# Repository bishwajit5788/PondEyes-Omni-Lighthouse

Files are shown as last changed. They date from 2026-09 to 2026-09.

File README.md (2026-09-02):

# PondEyes Omni-Lighthouse: 360-Degree Multi-Target Radar Platform

[]()
[]()
[]()
[]()
[]()

**PondEyes Omni-Lighthouse** is a high-precision, 360-degree multi-target tracking radar platform engineered for panoramic spatial awareness. It integrates six **Hi-Link HLK-LD2450 24GHz FMCW mmWave radar sensors** arranged radially at 60° increments inside an isolated 6-compartment waveguide cylinder. 

The system leverages a **two-stage distributed embedded architecture**: two high-speed **Teensy 4.1** microcontrollers handle real-time 256k-baud UART frame parsing, trigonometric rotation, and Euclidean seam deduplication, while a **Seeed Studio XIAO ESP32-S3** master coordinator aggregates fused binary streams over an 8 MHz SPI bus and broadcasts structured JSON telemetry over Wi-Fi/MQTT at 10 Hz.

---

## Table of Contents
1. [Architecture & Hardware Bug Fixes](#architecture--hardware-bug-fixes)
2. [Waveguide Hollow Cylinder & RF Isolation](#waveguide-hollow-cylinder--rf-isolation)
3. [Power Management (1S4P Matrix + MT3608)](#power-management-1s4p-matrix--mt3608)
4. [Hardware Pinout & Interconnects](#hardware-pinout--interconnects)
5. [Coordinate Geometry & Rotation Matrix](#coordinate-geometry--rotation-matrix)
6. [Boundary Seam Deduplication & SVG Overlay](#boundary-seam-deduplication--svg-overlay)
7. [MQTT Data Stream Schema](#mqtt-data-stream-schema)
8. [Building & Flashing](#building--flashing)
9. [Configuration Reference](#configuration-reference)

---

## Architecture & Hardware Bug Fixes

```
 ┌────────────────────────────────────────────────────────────────────────────────────────┐
 │                              STAGE 1: REAL-TIME DSP & FUSION                           │
 ├─────────────────────────────────────────┬──────────────────────────────────────────────┤
 │             TEENSY 4.1 (NODE A)         │              TEENSY 4.1 (NODE B)             │
 │          600 MHz ARM Cortex-M7          │           600 MHz ARM Cortex-M7              │
 │                                         │                                              │
 │  [S1 @ 0°]   [S2 @ 60°]   [S3 @ 120°]   │  [S4 @ 180°]  [S5 @ 240°]  [S6 @ 300°]       │
 │   Serial1      Serial2      Serial3     │    Serial1       Serial2      Serial3        │
 │  (256kbaud)   (256kbaud)   (256kbaud)   │   (256kbaud)    (256kbaud)   (256kbaud)      │
 │      │            │            │        │       │             │            │           │
 │      ▼            ▼            ▼        │       ▼             ▼            ▼           │
 │  ┌───────────────────────────────────┐  │  ┌────────────────────────────────────────┐  │
 │  │ 3x UART Ring Buffers (Zero Drops) │  │  │  3x UART Ring Buffers (Zero Drops)     │  │
 │  │ LD2450 Sign-Magnitude Decoders    │  │  │  LD2450 Sign-Magnitude Decoders        │  │
 │  │ 2D Rotation Matrix (0°/60°/120°)  │  │  │  2D Rotation Matrix (180°/240°/300°)   │  │
 │  │ Euclidean Seam Deduplication      │  │  │  Euclidean Seam Deduplication          │  │
 │  │ TSPISlave + Tri-State MISO        │  │  │  TSPISlave + Tri-State MISO            │  │
 │  └─────────────────┬─────────────────┘  │  └───────────────────┬────────────────────┘  │
 └────────────────────┼────────────────────┴──────────────────────┼───────────────────────┘
                      │ (SPI Bus + CS_A + DRDY_A)                 │ (SPI Bus + CS_B + DRDY_B)
                      └─────────────────────────┬─────────────────┘
                                                ▼
 ┌────────────────────────────────────────────────────────────────────────────────────────┐
 │                      STAGE 2: MASTER COORDINATOR & BROADCASTER                         │
 ├────────────────────────────────────────────────────────────────────────────────────────┤
 │                             SEEED STUDIO XIAO ESP32-S3                                 │
 │                              240 MHz Dual-Core LX7                                     │
 │                                                                                        │
 │   • High-Speed Hardware SPI Master Engine (8 MHz Bus Clock)                            │
 │   • Deterministic Multi-Node CS Arbitration & Hardware DRDY Interrupt Handshake        │
 │   • CRC16 Verification & Frame Synchronization                                         │
 │   • Exponential Backoff Wi-Fi Reconnection & Hardware Watchdog                         │
 │   • Zero-Heap-Leak Static Memory (StaticJsonDocument<2048>) @ 10 Hz                    │
 └──────────────────────────────────────────────┬─────────────────────────────────────────┘
                                                │ (10Hz Wi-Fi MQTT)
                                                ▼
 ┌────────────────────────────────────────────────────────────────────────────────────────┐
 │ MQTT BROKER / PONDEYES DASHBOARD                                                       │
 │ Topics: PondEyes/lighthouse/S1..S6  |  PondEyes/lighthouse/fused                       │
 └────────────────────────────────────────────────────────────────────────────────────────┘
```

### Critical Bug Fixes Implemented:
1. **Teensy SPI Hardware Compatibility (`TSPISlave.h`)**:
   - Replaced deprecated SPI slave declarations with `TSPISlave` register-level drivers targeting the i.MX RT1062 LPSPI peripheral.
2. **MISO Line Collision Prevention (Active Tri-State Switching)**:
   - When CS is HIGH (deselected), each Teensy immediately configures its hardware MISO pin (Pin 12) to high-impedance floating mode (`pinMode(12, INPUT);`).
   - MISO is driven as `OUTPUT` (`pinMode(12, OUTPUT);`) **only** when its specific CS line is pulled LOW by the ESP32-S3 master, preventing electrical contention on the shared MISO bus.
3. **Zero-Heap-Leak Static Memory Architecture on ESP32-S3**:
   - Eliminated dynamic heap allocation in the 10 Hz broadcast loop by utilizing a static fixed buffer (`StaticJsonDocument<2048> doc;`), completely preventing heap fragmentation and watchdog resets.
4. **Strict Configuration Validation**:
   - `radar_config.json` fully defines `arena.dimensions_mm: [10000, 10000]` and `arena.center_grid_mm: [5000, 5000]` alongside native integer pin maps.

---

## Waveguide Hollow Cylinder & RF Isolation

The physical chassis of the Omni-Lighthouse consists of a **130 mm diameter hollow cylinder** partitioned into **six 60° isolated radial compartments**.

```
                           [ S1 (0°) ]
                             ▲  ▲
                           /  ││  \
              [ S6 (300°) ] /───┼───\ [ S2 (60°) ]
                   ◄──     │ 1 │ 2 │     ──►
                   ◄──     │───┼───│     ──►
                           │ 6 │ 3 │
              [ S5 (240°) ] \───┼───/ [ S3 (120°) ]
                           \  ││  /
                             ▼  ▼
                          [ S4 (180°) ]
```

### RF Cross-Talk Mitigation:
1. **Operating Band**: 24.00 GHz – 24.25 GHz FMCW radar.
2. **Azimuth FOV**: Each sensor has an effective horizontal beamwidth of ±60° (120° total).
3. **Internal Waveguide Septa**: Each compartment features a 35 mm deep conductive barrier lined with 0.1 mm copper shielding tape to prevent direct line-of-sight transmit lobe bleed into neighboring radar receiver antennas.
4. **Antenna Mounting Radius ($R = 65.0\text{ mm}$)**: Sensor apertures sit flush with the cylinder perimeter.

---

## Power Management (1S4P Matrix + MT3608)

```
 ┌──────────────────────┐      ┌─────────────────────────┐      ┌──────────────────────┐
 │  1S4P 18650 Matrix   │ 3.7V │     MT3608 Step-Up      │ 5.0V │   LC Filter + Rail   │
 │   3.0V - 4.2V Nom    ├─────►│     Boost Converter     ├─────►│ L: 10µH, C: 470µF    ├──► 5V Rail
 │  14,000 mAh (51.8Wh) │      │ (Set: 5.05V, max 3.0A)  │      │ (Decoupling per node)│
 └──────────────────────┘      └─────────────────────────┘      └──────────────────────┘
```

### Power Specifications:
| Subsystem | Operating Voltage | Peak Current | Avg Current | Notes |
| :--- | :--- | :--- | :--- | :--- |
| **6x HLK-LD2450 Radars** | 5.0 V DC | 6x 120 mA = 720 mA | ~550 mA | 24GHz FMCW RF transceivers |
| **2x Teensy 4.1 Nodes** | 5.0 V DC (VIN) | 2x 150 mA = 300 mA | ~200 mA | 600 MHz Cortex-M7 |
| **1x XIAO ESP32-S3** | 5.0 V DC (5V pin) | 350 mA (Wi-Fi TX) | ~120 mA | 2.4GHz 802.11 b/g/n active |
| **Total System Draw** | **5.0 V Rail** | **~1.37 A Peak** | **~870 mA Avg** | **~4.35 Watts** |

- **Battery Matrix**: 1S4P 18650 cells (14,000 mAh @ 3.7V = 51.8 Wh).
- **Runtime**: **10.8 to 14.5 Hours** continuous operation.
- **LC Low-Pass Filter**: $10\mu\text{H}$ inductor + $470\mu\text{F}$ low-ESR capacitor eliminates 1.2 MHz MT3608 switching ripple ($< 15\text{ mV}_\text{p-p}$).

---

## Hardware Pinout & Interconnects

### 1. Teensy 4.1 Node A (Sensors 1, 2, 3)
| Function | Teensy 4.1 Pin | Connected Device | Description |
| :--- | :--- | :--- | :--- |
| **Serial1 RX** | Pin 0 (RX1) | S1 (0°) TX | Sensor 1 256k-baud UART |
| **Serial1 TX** | Pin 1 (TX1) | S1 (0°) RX | Sensor 1 Config (Optional) |
| **Serial2 RX** | Pin 7 (RX2) | S2 (60°) TX | Sensor 2 256k-baud UART |
| **Serial2 TX** | Pin 8 (TX2) | S2 (60°) RX | Sensor 2 Config (Optional) |
| **Serial3 RX** | Pin 14 (RX3)| S3 (120°) TX | Sensor 3 256k-baud UART |
| **Serial3 TX** | Pin 15 (TX3)| S3 (120°) RX | Sensor 3 Config (Optional) |
| **SPI CS** | Pin 10 | XIAO D1 (GPIO 2) | SPI Slave Select (Active LOW) |
| **SPI MOSI** | Pin 11 | XIAO D10 (GPIO 9)| SPI Data In from Master |
| **SPI MISO** | Pin 12 | XIAO D9 (GPIO 8) | Tri-State MISO Data Out |
| **SPI SCK** | Pin 13 | XIAO D8 (GPIO 7) | SPI Clock (8 MHz) |
| **DRDY Handshake**| Pin 2 | XIAO D3 (GPIO 4) | Data Ready Handshake Line |
| **Power VIN** | VIN (5V) | 5.0V Boost Rail | System 5V Power Supply |
| **Ground** | GND | Common Ground | Unified Ground Plane |

### 2. Teensy 4.1 Node B (Sensors 4, 5, 6)
| Function | Teensy 4.1 Pin | Connected Device | Description |
| :--- | :--- | :--- | :--- |
| **Serial1 RX** | Pin 0 (RX1) | S4 (180°) TX | Sensor 4 256k-baud UART |
| **Serial1 TX** | Pin 1 (TX1) | S4 (180°) RX | Sensor 4 Config (Optional) |
| **Serial2 RX** | Pin 7 (RX2) | S5 (240°) TX | Sensor 5 256k-baud UART |
| **Serial2 TX** | Pin 8 (TX2) | S5 (240°) RX | Sensor 5 Config (Optional) |
| **Serial3 RX** | Pin 14 (RX3)| S6 (300°) TX | Sensor 6 256k-baud UART |
| **Serial3 TX** | Pin 15 (TX3)| S6 (300°) RX | Sensor 6 Config (Optional) |
| **SPI CS** | Pin 10 | XIAO D2 (GPIO 3) | SPI Slave Select (Active LOW) |
| **SPI MOSI** | Pin 11 | XIAO D10 (GPIO 9)| SPI Data In from Master |
| **SPI MISO** | Pin 12 | XIAO D9 (GPIO 8) | Tri-State MISO Data Out |
| **SPI SCK** | Pin 13 | XIAO D8 (GPIO 7) | SPI Clock (8 MHz) |
| **DRDY Handshake**| Pin 2 | XIAO D4 (GPIO 5) | Data Ready Handshake Line |
| **Power VIN** | VIN (5V) | 5.0V Boost Rail | System 5V Power Supply |
| **Ground** | GND | Common Ground | Unified Ground Plane |

### 3. Seeed Studio XIAO ESP32-S3 Master Coordinator
| Function | XIAO Pin | Connected Device | Description |
| :--- | :--- | :--- | :--- |
| **SPI SCK** | D8 (GPIO 7) | Node A Pin 13 & Node B Pin 13 | Master SPI Clock (8 MHz) |
| **SPI MISO**| D9 (GPIO 8) | Node A Pin 12 & Node B Pin 12 | Shared Master SPI MISO In |
| **SPI MOSI**| D10 (GPIO 9)| Node A Pin 11 & Node B Pin 11 | Shared Master SPI MOSI Out |
| **CS Node A**| D1 (GPIO 2) | Node A Pin 10 | Node A Chip Select |
| **CS Node B**| D2 (GPIO 3) | Node B Pin 10 | Node B Chip Select |
| **DRDY Node A**| D3 (GPIO 4) | Node A Pin 2 | Node A Data Ready Interrupt |
| **DRDY Node B**| D4 (GPIO 5) | Node B Pin 2 | Node B Data Ready Interrupt |
| **Status LED** | LED_BUILTIN (GPIO 21) | Onboard LED | Connection / Error Indicator |
| **Power 5V** | 5V Pin | 5.0V Boost Rail | System 5V Power Supply |
| **Ground** | GND | Common Ground | Unified Ground Plane |

---

## Coordinate Geometry & Rotation Matrix

- **Arena Center**: $(X_c, Y_c) = (5000.0\text{ mm}, 5000.0\text{ mm})$.
- **Sensor Radius**: $R = 65.0\text{ mm}$.
- **Sensor Angles $\theta_k$**: $0^\circ, 60^\circ, 120^\circ, 180^\circ, 240^\circ, 300^\circ$ clockwise from North ($+Y$).

$$\mathbf{X_{\text{global}}} = X_c + R \cdot \sin(\theta_k) + X_{\text{local}} \cdot \cos(\theta_k) + Y_{\text{local}} \cdot \sin(\theta_k)$$
$$\mathbf{Y_{\text{global}}} = Y_c + R \cdot \cos(\theta_k) - X_{\text{local}} \cdot \sin(\theta_k) + Y_{\text{local}} \cdot \cos(\theta_k)$$

---

## Boundary Seam Deduplication & SVG Overlay

Adjacent sensors overlap by 60° across boundary seams (at 30°, 90°, 150°, 210°, 270°, 330°). If distance between detections from different sensors is $< 500\text{ mm}$, they are fused into a single track $(\frac{X_i+X_j}{2}, \frac{Y_i+Y_j}{2})$.

### Dashboard SVG Overlay Code (`map.svg`):
```xml
<svg viewBox="0 0 10000 10000" width="100%" height="100%" xmlns="http://www.w3.org/2000/svg">
  <!-- Unified Arena Grid -->
  <rect width="10000" height="10000" fill="#0D1117" stroke="#30363D" stroke-width="2"/>
  
  <!-- Boundary Seam Rays for Visual Calibration -->
  <g id="seam-overlays" stroke="#FF2A2A" stroke-width="0.75pt" stroke-dasharray="4 2">
    <!-- Seam 1: 30° -->
    <line x1="5000" y1="5000" x2="8000" y2="10196" />
    <!-- Seam 2: 90° -->
    <line x1="5000" y1="5000" x2="11000" y2="5000" />
    <!-- Seam 3: 150° -->
    <line x1="5000" y1="5000" x2="8000" y2="-196" />
    <!-- Seam 4: 210° -->
    <line x1="5000" y1="5000" x2="2000" y2="-196" />
    <!-- Seam 5: 270° -->
    <line x1="5000" y1="5000" x2="-1000" y2="5000" />
    <!-- Seam 6: 330° -->
    <line x1="5000" y1="5000" x2="2000" y2="10196" />
  </g>
  
  <!-- Central Lighthouse Body -->
  <circle cx="5000" cy="5000" r="65" fill="#58A6FF" stroke="#FFFFFF" stroke-width="2"/>
</svg>
```

---

## MQTT Data Stream Schema

### Fused Telemetry Topic (`PondEyes/lighthouse/fused` @ 10 Hz)
```json
{
  "system": "PondEyes Omni-Lighthouse",
  "timestamp_ms": 145230,
  "rate_hz": 10,
  "total_active_targets": 2,
  "fused_targets": [
    {
      "sensor": 1,
      "track_id": 1,
      "x": 5120,
      "y": 7450,
      "speed": -24,
      "distance": 2450,
      "fused": false,
      "source_mask": 1
    },
    {
      "sensor": 2,
      "track_id": 1,
      "x": 6850,
      "y": 6200,
      "speed": 0,
      "distance": 2150,
      "fused": true,
      "source_mask": 3
    }
  ]
}
```

---

## Building & Flashing

```bash
# Build all firmware binaries
pio run

# Flash Teensy Node A
pio run -e teensy_node_a --target upload

# Flash Teensy Node B
pio run -e teensy_node_b --target upload

# Flash Seeed Studio XIAO ESP32-S3
pio run -e xiao_broadcaster --target upload
```

---

## Live 360° Tracking Canvas & Simulator

Run the real-time PyGame 360° tracking canvas and mock radar telemetry generator:

```bash
# 1. Install dependencies
pip install pygame paho-mqtt

# 2. Run the radar telemetry simulator (10 Hz mock feed)
python3 simulate_radar.py

# 3. In another terminal, launch the live visualization canvas
python3 main.py
```

---

## License

Distributed under the MIT License. See `LICENSE` for details.

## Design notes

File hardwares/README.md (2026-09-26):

# PondEyes Omni-Lighthouse — Hardware Inventory

This directory contains photographs of the physical hardware received for the PondEyes Omni-Lighthouse prototype.

## Hardware Photo Inventory

### 01 — HLK-LD2450 Radar Modules

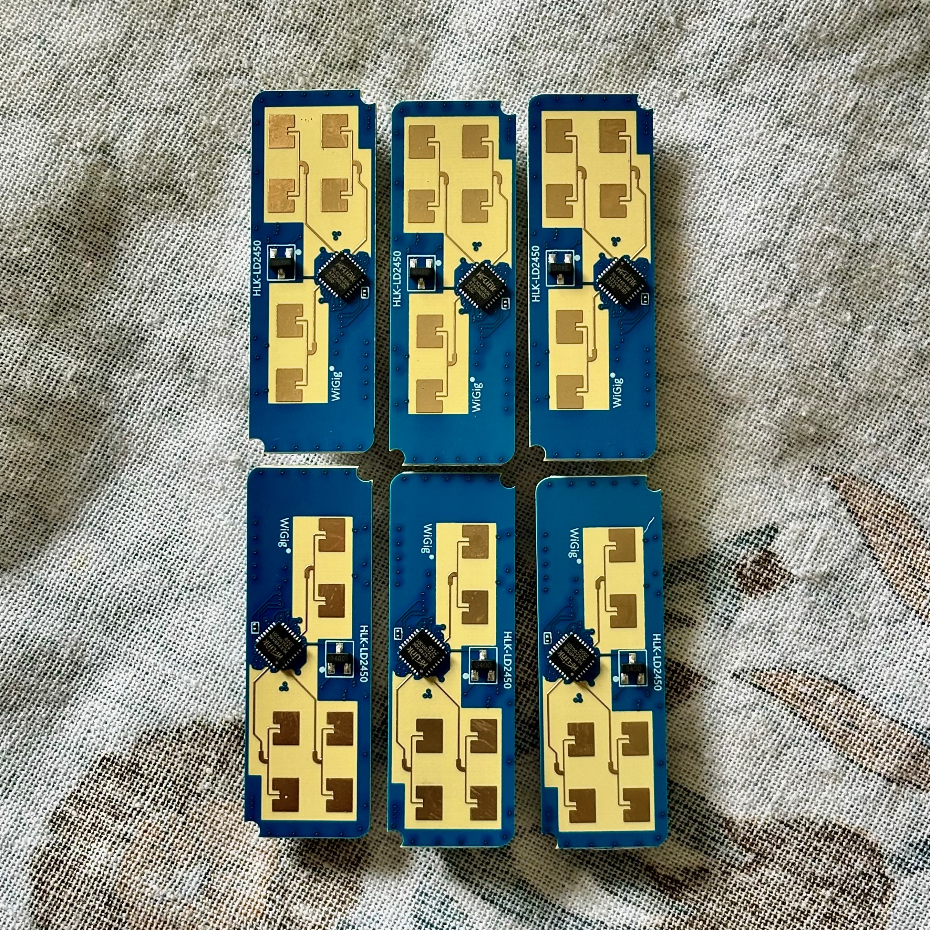
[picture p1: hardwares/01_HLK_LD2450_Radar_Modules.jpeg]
Six HLK-LD2450 radar modules


**File:**
`01_HLK_LD2450_Radar_Modules.jpeg`

**Description:**
Photograph showing six Hi-Link HLK-LD2450 24 GHz FMCW radar modules.

**Quantity visible:**
6

**Component:**
Hi-Link HLK-LD2450

**Role in PondEyes:**
Six radar modules are used as the distributed 360-degree sensing array, positioned around the cylindrical enclosure at 60-degree angular intervals.

**Important:**
The photograph documents the physical modules received. Do not claim electrical specifications that cannot be established from the photograph alone.

---

### 02 — 18650 Battery Cells and BMS

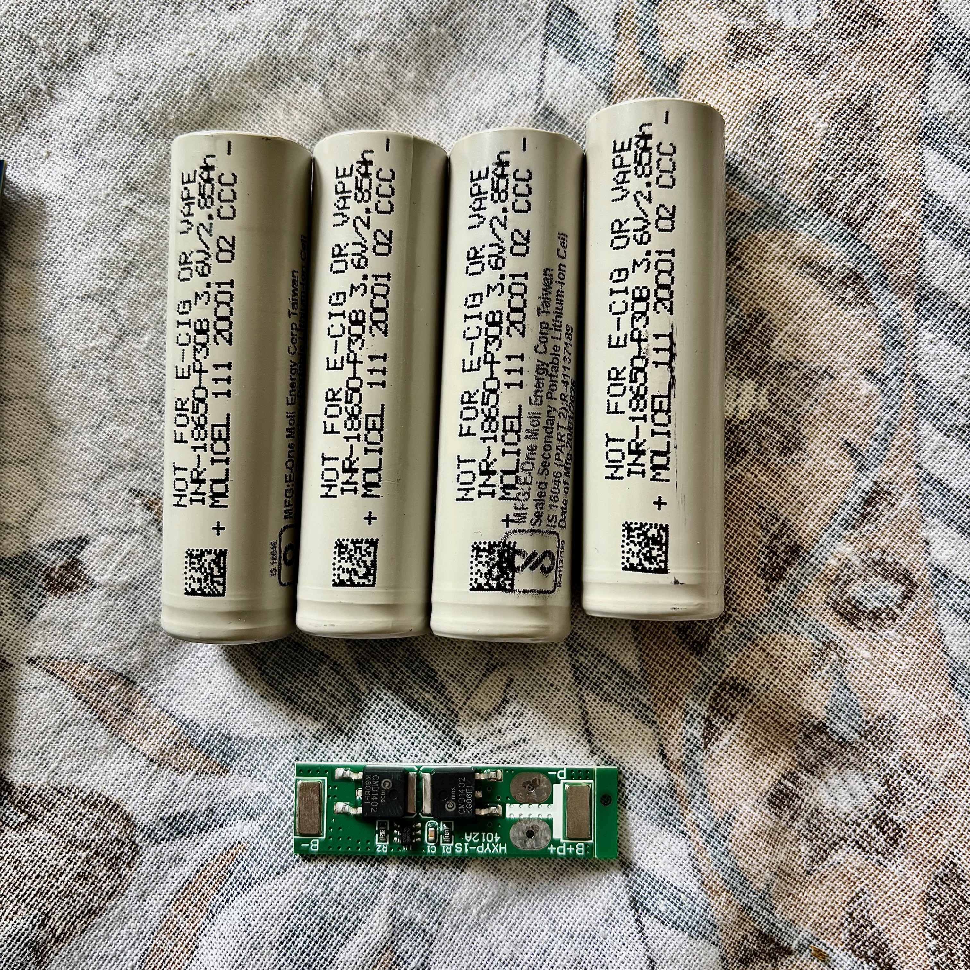
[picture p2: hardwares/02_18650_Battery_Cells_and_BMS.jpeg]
Four 18650 battery cells and battery protection/BMS PCB


**File:**
`02_18650_Battery_Cells_and_BMS.jpeg`

**Description:**
Photograph showing four cylindrical 18650 lithium-ion cells and a small battery protection/BMS PCB.

**Visible components:**
- 4 × 18650 cylindrical Li-ion cells
- 1 × battery protection/BMS PCB

**Visible cell markings:**
- `NOT FOR E-CIG OR VAPE`
- `INR-18650-P30B 3.6V/2.85Ah`
- `+ MOLICEL 111 20C01 02 CCC -`
- `MFG: E-One Moli Energy Corp Taiwan`
- `Sealed Secondary Portable Lithium-ion Cell`
- `IS 16046 (PART 2)/IEC 62133-2`
- `Date of Mfg 20/01/2026`

**BMS PCB note:**
Visible silkscreen marking indicates `HXYP-1S-4012A` with solder pads `B-`, `B+`, `P+`, `P-`. Exact BMS model/rating requires verification from the PCB marking or datasheet.

---

### 03 — AiSHi Electrolytic Capacitors

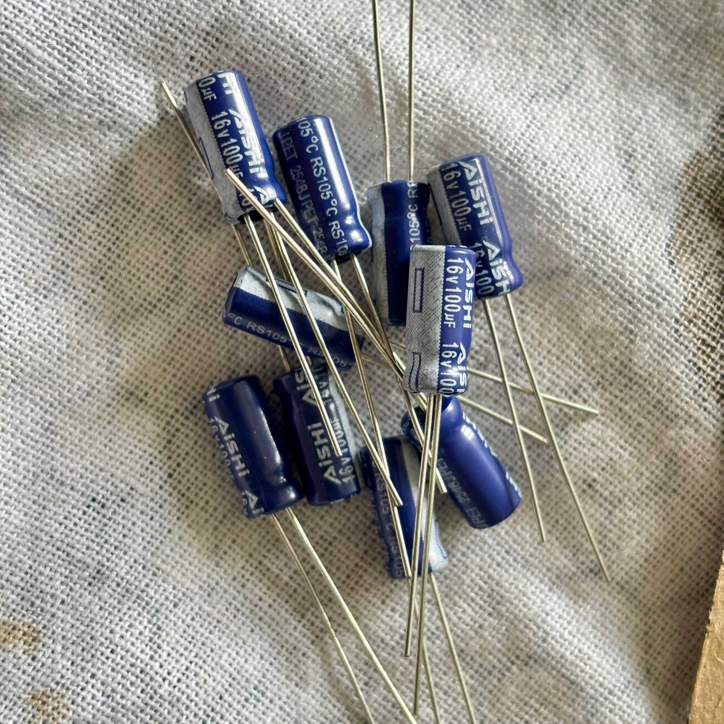
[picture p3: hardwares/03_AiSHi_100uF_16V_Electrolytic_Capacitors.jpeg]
Blue AiSHi electrolytic capacitors marked 100µF 16V


**File:**
`03_AiSHi_100uF_16V_Electrolytic_Capacitors.jpeg`

**Description:**
Photograph showing blue radial electrolytic capacitors.

**Visible marking:**
- `AiSHi`
- `100µF`
- `16V`
- `105°C RS105°C`
- `2548J PET`

**Component:**
AiSHi 100 µF, 16 V electrolytic capacitor.

**Purpose in the PondEyes design:**
Power-rail bulk/decoupling capacitance associated with the sensor/electronics power system.

**Quantity visible:**
Multiple visible (loose radial leads). Visible quantity: not conclusively countable from photograph alone.

---

### 04 — 0.1µF 35V Tantalum Capacitors

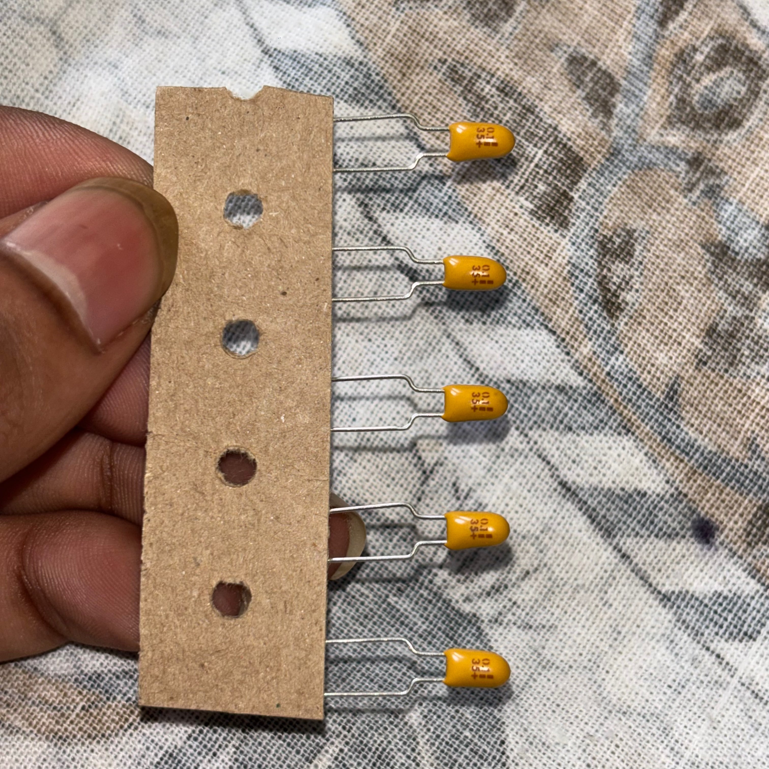
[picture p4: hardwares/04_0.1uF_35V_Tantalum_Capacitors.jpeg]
Yellow axial/lead capacitors on cardboard strip


**File:**
`04_0.1uF_35V_Tantalum_Capacitors.jpeg`

**Description:**
Photograph showing yellow axial/lead capacitors mounted on a temporary cardboard strip.

**Visible marking:**
- `0.1µF`
- `35V`

**Component:**
0.1 µF, 35 V capacitor.

**Package / Style:**
Yellow bead / dipped radial-lead capacitor mounted on a punched cardboard component carrier strip.

**Note:**
Documented exactly as visible. No specific manufacturer markings are established from the photograph alone. Electrical behavior is documented only to the marked 0.1 µF, 35 V rating.

---

### 05 — Teensy, XIAO ESP32-S3, Antenna and RF Hardware

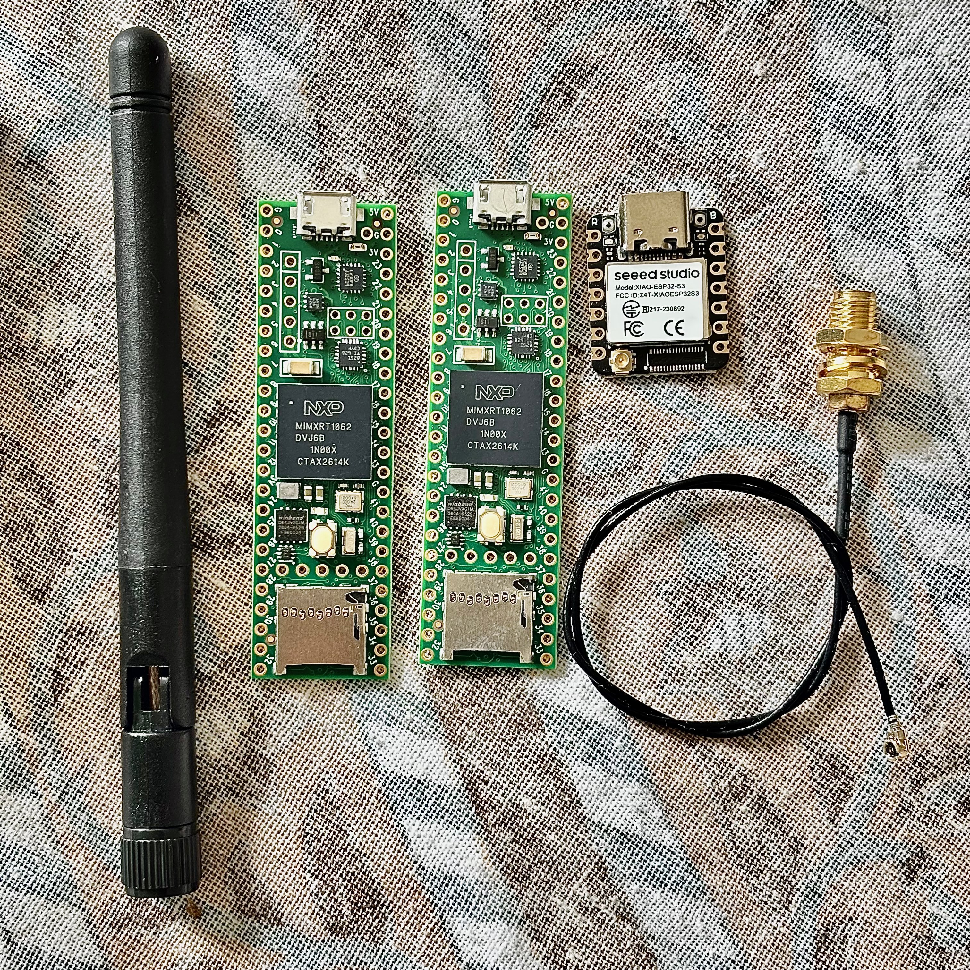
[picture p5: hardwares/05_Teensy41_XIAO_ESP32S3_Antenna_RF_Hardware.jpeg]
Two Teensy 4.1 boards, XIAO ESP32-S3, external antenna and RF coaxial hardware


**File:**
`05_Teensy41_XIAO_ESP32S3_Antenna_RF_Hardware.jpeg`

**Description:**
Photograph showing:
- 2 × Teensy 4.1 development boards (NXP MIMXRT1062 processor)
- 1 × Seeed Studio XIAO ESP32-S3 development board (Model: XIAO-ESP32-S3, FCC ID: Z4T-XIAOESP32S3)
- 1 × external antenna
- RF coaxial cable
- RF connector/bulkhead hardware

**Role in PondEyes:**
- The Teensy boards are the two primary radar-processing/controller boards in the PondEyes architecture.
- The XIAO ESP32-S3 is the network/broadcast controller.
- The antenna and coaxial hardware are intended for the wireless/RF interface.

Do not infer connector standards unless visible markings or dimensions establish them.

---

### 06 — Complete PondEyes Hardware Inventory

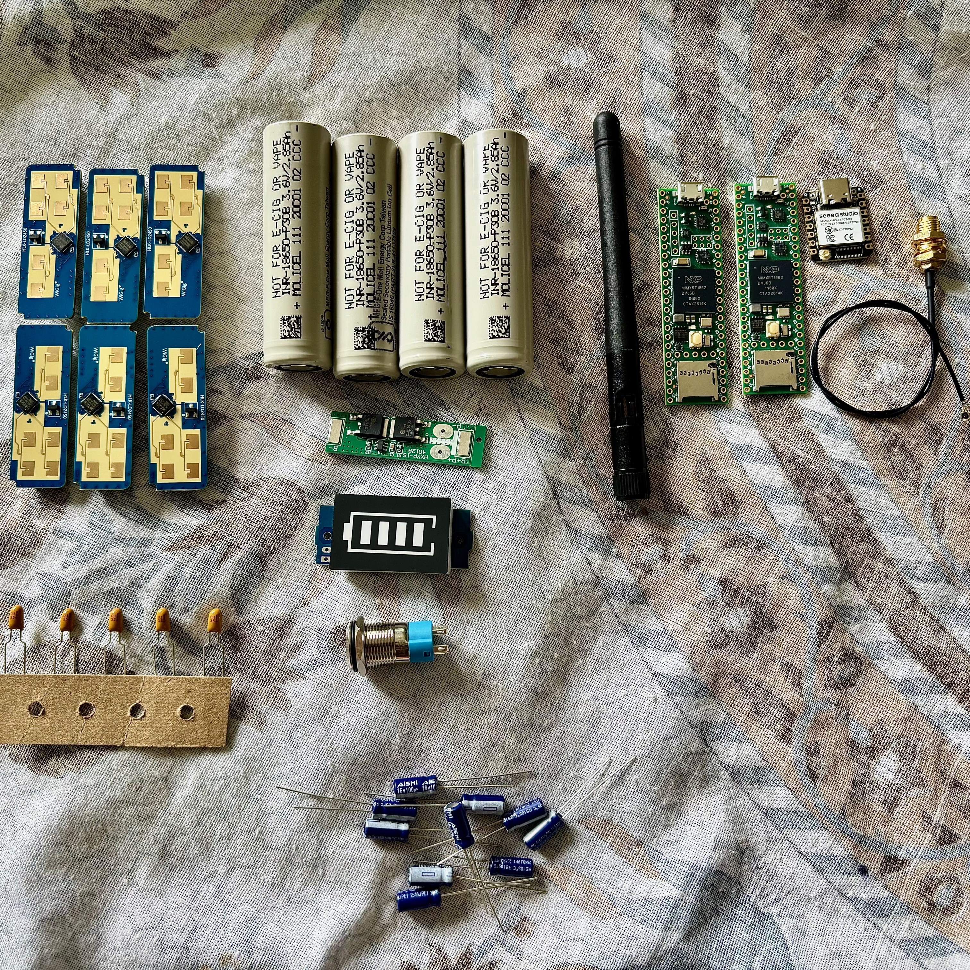
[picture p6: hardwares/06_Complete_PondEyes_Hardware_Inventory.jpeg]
Overall PondEyes hardware inventory showing major components together


**File:**
`06_Complete_PondEyes_Hardware_Inventory.jpeg`

**Description:**
Overall photograph documenting the physical hardware received for the PondEyes Omni-Lighthouse prototype.

The photograph includes the major hardware groups:
- 6 × HLK-LD2450 radar modules
- 18650 battery cells
- Battery protection/BMS PCB
- Teensy 4.1 boards
- XIAO ESP32-S3
- External antenna
- RF cable/connector hardware
- Electrolytic capacitors
- Yellow capacitors
- Battery indicator/display module
- Panel-mount switch/button
- Additional visible prototype electronics/components

Only identify a component specifically when it is clearly visible or established by its marking.

---

## Component Summary Table

| Category | Component | Quantity Visible | Purpose |
|---|---|---:|---|
| Radar | Hi-Link HLK-LD2450 | 6 | 24 GHz radar sensing |
| Controller | Teensy 4.1 | 2 | Radar data processing/aggregation |
| Network Controller | Seeed Studio XIAO ESP32-S3 | 1 | Wireless/network broadcasting |
| Battery | 18650 Li-ion cells | 4 | Battery energy storage |
| Protection | Battery BMS/protection PCB | 1 visible | Battery protection |
| Bulk capacitor | AiSHi 100 µF 16 V electrolytic | Multiple visible | Power filtering/decoupling |
| Decoupling capacitor | 0.1 µF 35 V capacitors | Multiple visible | High-frequency decoupling |
| RF | External antenna | 1 | Wireless/RF interface |
| RF hardware | Coax/connector/bulkhead | 1 set visible | RF connection |
| User interface | Panel-mount switch/button | 1 visible | Power/control interface |
| Indicator | Battery indicator/display | 1 visible | Battery status indication |

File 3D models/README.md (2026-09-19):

# PondEyes Omni-Lighthouse — 3D Models

This directory contains the mechanical CAD exports and dimensional reference for the PondEyes Omni-Lighthouse enclosure.

## 3D model files

### Blender source files

The `.blend` files are the editable Blender source models used to create the corresponding STL exports.

- `bottom_tot.blend` — editable Blender source for the bottom service-cap assembly
- `sensor_tot.blend` — editable Blender source for the six-sensor external mounting assembly
- `top_tot.blend` — editable Blender source for the top cap assembly

### STL exports

The STL files are the 3D-printable mesh exports corresponding to the Blender source files.

- `top_tot.stl` — top cap export
- `sensor_tot.stl` — six-sensor external mounting export
- `bottom_tot.stl` — bottom service-cap export

### Documentation

- `PondEyes_Enclosure_Spec.md` — hardware and enclosure dimensions

## Source-to-STL mapping

| Blender source | STL export | Purpose |
|---|---|---|
| `top_tot.blend` | `top_tot.stl` | Top cap |
| `sensor_tot.blend` | `sensor_tot.stl` | Six-radar sensor mounting body |
| `bottom_tot.blend` | `bottom_tot.stl` | Bottom service cap |

## Mechanical target

**100 mm outer diameter × 150 mm body height × 3 mm nominal wall**

Six HLK-LD2450 radar modules are arranged externally at 60° intervals. Two Teensy 4.1 boards and one XIAO ESP32-S3 are intended to fit inside the enclosure.

## CAD workflow

The recommended workflow is:

1. Edit the corresponding `.blend` source in Blender.
2. Verify dimensions, clearances, manifold geometry, and assembly interfaces.
3. Export the updated component as STL for slicing/3D printing.
4. Keep the Blender source and STL export together so the printable mesh remains traceable to its editable CAD source.

> **Note:** The Blender files are the editable design sources; the STL files are mesh exports intended for fabrication and should not be treated as the primary editable CAD source.

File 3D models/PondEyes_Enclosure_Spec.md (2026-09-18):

# PondEyes Omni-Lighthouse — 3D Model & Hardware Specification

## Current enclosure target

- Main body: cylindrical handheld enclosure
- Main body outer diameter: 100 mm
- Outer radius: 50 mm
- Nominal wall thickness: 3 mm
- Inner diameter: 94 mm
- Inner radius: 47 mm
- Main body height: 150 mm
- Printer target: Bambu Lab A1
- Nozzle: 0.4 mm

## Radar sensors

### Hi-Link HLK-LD2450

- Quantity: 6
- Module dimensions: 44 mm × 15 mm
- Mounting: external, low-profile cradles
- Sensor angles: 0°, 60°, 120°, 180°, 240°, 300°
- Opposing pairs: S1/S4, S2/S5, S3/S6
- Nominal sensor fit envelope with 0.2 mm per-side clearance: 44.4 mm × 15.4 mm

## Development boards

### Teensy 4.1

- Quantity: 2
- Approximate board dimensions: 61 mm × 17.8 mm
- Mounted internally
- Internal holder/rail system should preserve service access and wiring clearance

### Seeed Studio XIAO ESP32-S3

- Quantity: 1
- Board dimensions: 21 mm × 17.8 mm
- Mounted internally
- Associated with the top/antenna assembly

## Caps

### Top cap

- Removable
- Hollow internal volume
- Centered antenna pass-through/support
- Antenna hole target: Ø6.5 mm

### Bottom service cap

- Removable
- Closed bottom surface
- Hollow interior
- Female helical thread on the inside of the cap
- Mates with the enclosure's external male helical thread
- Intended to lock/unlock by rotation
- Thread fit must be validated physically for the selected FDM material and print orientation

## CAD / manufacturing notes

The STL exports are the current supplied CAD revision. Before fabrication, verify the STL dimensions against the master dimensions above and perform a test print of the threaded interface. RF performance and radar-to-radar interference are not proven by mechanical CAD alone.

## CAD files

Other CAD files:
3D models/sensor_tot.stl
3D models/bottom_tot.stl
3D models/top_tot.stl

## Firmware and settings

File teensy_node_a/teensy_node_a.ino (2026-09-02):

/**
 * ============================================================================
 * PondEyes Omni-Lighthouse - Teensy Node A Firmware
 * Microcontroller: Teensy 4.1 (600 MHz ARM Cortex-M7)
 * ============================================================================
 */

#if __has_include(<Arduino.h>)
#include <Arduino.h>
#endif
#if __has_include(<WProgram.h>)
#include <WProgram.h>
#endif
#if __has_include(<usb_serial.h>)
#include <usb_serial.h>
#endif
#if __has_include(<HardwareSerial.h>)
#include <HardwareSerial.h>
#endif
#if __has_include(<Stream.h>)
#include <Stream.h>
#endif
#if __has_include(<SPI.h>)
#include <SPI.h>
#endif
#if __has_include(<TSPISlave.h>)
#include <TSPISlave.h>
#endif
#include <math.h>
#include <string.h>
#include <stdint.h>
#include <stdbool.h>

// Arduino Core Timing & Utility Prototypes (C-linkage for IDE / Clangd / Toolchains)
#ifdef __cplusplus
extern "C" {
#endif
void delay(uint32_t ms);
void delayMicroseconds(uint32_t us);
unsigned long millis(void);
unsigned long micros(void);
void yield(void);
#ifdef __cplusplus
}
#endif

// Fallback declarations for IDE language servers / Clangd indexers when standalone
#if !defined(ARDUINO) && !defined(TEENSYDUINO)
#ifndef HIGH
#define HIGH 1
#define LOW  0
#endif
#ifndef INPUT
#define INPUT 0
#define OUTPUT 1
#define INPUT_PULLUP 2
#endif
#ifndef CHANGE
#define CHANGE 1
#define FALLING 2
#define RISING 3
#endif

#ifndef F
#define F(str) (str)
#endif

#ifdef __cplusplus
class Print {
public:
    virtual ~Print() {}
    virtual size_t write(uint8_t) = 0;
    virtual size_t write(const uint8_t*, size_t size) { return size; }
    size_t print(const char*) { return 0; }
    size_t print(char) { return 0; }
    size_t print(int, int = 10) { return 0; }
    size_t print(unsigned int, int = 10) { return 0; }
    size_t print(long, int = 10) { return 0; }
    size_t print(unsigned long, int = 10) { return 0; }
    size_t print(double, int = 2) { return 0; }
    size_t println(const char* = "") { return 0; }
    size_t println(char) { return 0; }
    size_t println(int, int = 10) { return 0; }
    size_t println(unsigned int, int = 10) { return 0; }
    size_t println(long, int = 10) { return 0; }
    size_t println(unsigned long, int = 10) { return 0; }
    size_t println(double, int = 2) { return 0; }
    int printf(const char*, ...) __attribute__((format(printf, 2, 3))) { return 0; }
};

class Stream : public Print {
public:
    virtual int available() = 0;
    virtual int read() = 0;
    virtual int peek() = 0;
    virtual void flush() {}
};

class HardwareSerial : public Stream {
public:
    void begin(uint32_t) {}
    void end() {}
    virtual int available() override { return 0; }
    virtual int read() override { return -1; }
    virtual int peek() override { return -1; }
    virtual void flush() override {}
    virtual size_t write(uint8_t) override { return 1; }
    using Print::write;
};

class usb_serial_class : public Stream {
public:
    void begin(uint32_t) {}
    void end() {}
    virtual int available() override { return 0; }
    virtual int read() override { return -1; }
    virtual int peek() override { return -1; }
    virtual void flush() override {}
    virtual size_t write(uint8_t) override { return 1; }
    using Print::write;
    operator bool() { return true; }
};

extern usb_serial_class Serial;
extern HardwareSerial Serial1;
extern HardwareSerial Serial2;
extern HardwareSerial Serial3;
#endif // __cplusplus
#endif // !defined(ARDUINO) && !defined(TEENSYDUINO)

#if __has_include("../include/pondeyes_protocol.h")
#include "../include/pondeyes_protocol.h"
#elif __has_include("include/pondeyes_protocol.h")
#include "include/pondeyes_protocol.h"
#else
#include "pondeyes_protocol.h"
#endif

// ============================================================================
// HARDWARE PIN DEFINITIONS & CONSTANTS
// ============================================================================
#define NODE_ID                     NODE_ID_A

// Teensy 4.1 Hardware SPI0 Pins
#define PIN_SPI_CS                  10  // SPI Chip Select (Input from ESP32-S3)
#define PIN_SPI_MOSI                11  // SPI MOSI (Input from ESP32-S3)
#define PIN_SPI_MISO                12  // SPI MISO (Tri-state Output to ESP32-S3)
#define PIN_SPI_SCK                 13  // SPI Clock (Input from ESP32-S3)
#define PIN_SPI_DRDY                2   // Data Ready Handshake (Output to ESP32-S3)
#define PIN_STATUS_LED              13  // Onboard Diagnostic LED

// Sensor Mapping for Node A
#define S1_ID                       1
#define S2_ID                       2
#define S3_ID                       3

#define S1_ANGLE_DEG                0.0f
#define S2_ANGLE_DEG                60.0f
#define S3_ANGLE_DEG                120.0f

#define DEG_TO_RAD_F                (3.14159265358979323846f / 180.0f)
#define PARSER_FRAME_LEN            30

// ============================================================================
// SENSOR PRECOMPUTED GEOMETRY TABLE
// ============================================================================
typedef struct {
    uint8_t  sensor_id;
    float    angle_deg;
    float    angle_rad;
    float    sin_val;
    float    cos_val;
    float    mount_x_mm;
    float    mount_y_mm;
} SensorGeometry_t;

static SensorGeometry_t g_sensors[3];

// ============================================================================
// LD2450 BINARY FRAME PARSER STATE MACHINE
// ============================================================================
typedef enum {
    STATE_WAIT_HEADER_0 = 0,
    STATE_WAIT_HEADER_1,
    STATE_WAIT_HEADER_2,
    STATE_WAIT_HEADER_3,
    STATE_READ_PAYLOAD,
    STATE_WAIT_TAIL_0,
    STATE_WAIT_TAIL_1
} ParserState_t;

typedef struct {
    HardwareSerial* serial;
    uint8_t         sensor_id;
    ParserState_t   state;
    uint8_t         payload_buf[24];
    uint8_t         payload_idx;
    uint32_t        packets_parsed;
    uint32_t        frame_errors;
    LD2450_RawTarget_t raw_targets[MAX_TARGETS_PER_SENSOR];
    bool            new_data_available;
} SensorPort_t;

static SensorPort_t g_ports[3];

// ============================================================================
// SPI SLAVE & PACKET BUFFERING
// ============================================================================
static TSPISlave           g_spi_slave = TSPISlave(SPI, PIN_SPI_MISO, PIN_SPI_MOSI, PIN_SPI_SCK, PIN_SPI_CS);
static PondEyesSpiPacket_t g_tx_packet;
static volatile bool       g_cs_active = false;
static volatile uint16_t   g_packet_sequence = 0;
static uint32_t            g_last_debug_print_ms = 0;

static PondEyesTarget_t    g_transformed_targets[MAX_TARGETS_PER_NODE];
static uint8_t             g_transformed_count = 0;

void init_sensor_geometry();
void init_uart_ports();
void init_spi_slave_interface();
void process_uart_port(SensorPort_t* port);
void parse_raw_payload(SensorPort_t* port);
void transform_targets_to_global();
void deduplicate_seam_targets();
void prepare_spi_packet();
void isr_cs_pin_transition();

void setup() {
    Serial.begin(115200);
    pinMode(PIN_STATUS_LED, OUTPUT);
    digitalWrite(PIN_STATUS_LED, HIGH);

    delay(1000);
    Serial.println(F("=================================================="));
    Serial.println(F(" PondEyes Omni-Lighthouse: TEENSY NODE A"));
    Serial.println(F(" Node ID: 0x0A | S1@0°, S2@60°, S3@120°"));
    Serial.println(F(" Baudrate: 256k | TSPISlave + Tri-State MISO"));
    Serial.println(F("=================================================="));

    init_sensor_geometry();
    init_uart_ports();
    init_spi_slave_interface();

    digitalWrite(PIN_STATUS_LED, LOW);
    Serial.println(F("[Node A] Initialization successful. System active."));
}

void init_sensor_geometry() {
    float angles[3] = { S1_ANGLE_DEG, S2_ANGLE_DEG, S3_ANGLE_DEG };
    uint8_t ids[3]  = { S1_ID, S2_ID, S3_ID };

    for (int i = 0; i < 3; i++) {
        g_sensors[i].sensor_id  = ids[i];
        g_sensors[i].angle_deg  = angles[i];
        g_sensors[i].angle_rad  = angles[i] * DEG_TO_RAD_F;
        g_sensors[i].sin_val    = sinf(g_sensors[i].angle_rad);
        g_sensors[i].cos_val    = cosf(g_sensors[i].angle_rad);
        g_sensors[i].mount_x_mm = LIGHTHOUSE_RADIUS_MM * g_sensors[i].sin_val;
        g_sensors[i].mount_y_mm = LIGHTHOUSE_RADIUS_MM * g_sensors[i].cos_val;
    }
}

void init_uart_ports() {
    Serial1.begin(LD2450_UART_BAUD);
    g_ports[0].serial = &Serial1;
    g_ports[0].sensor_id = S1_ID;
    g_ports[0].state = STATE_WAIT_HEADER_0;
    g_ports[0].payload_idx = 0;
    g_ports[0].packets_parsed = 0;
    g_ports[0].frame_errors = 0;
    g_ports[0].new_data_available = false;

    Serial2.begin(LD2450_UART_BAUD);
    g_ports[1].serial = &Serial2;
    g_ports[1].sensor_id = S2_ID;
    g_ports[1].state = STATE_WAIT_HEADER_0;
    g_ports[1].payload_idx = 0;
    g_ports[1].packets_parsed = 0;
    g_ports[1].frame_errors = 0;
    g_ports[1].new_data_available = false;

    Serial3.begin(LD2450_UART_BAUD);
    g_ports[2].serial = &Serial3;
    g_ports[2].sensor_id = S3_ID;
    g_ports[2].state = STATE_WAIT_HEADER_0;
    g_ports[2].payload_idx = 0;
    g_ports[2].packets_parsed = 0;
    g_ports[2].frame_errors = 0;
    g_ports[2].new_data_available = false;
}

void init_spi_slave_interface() {
    pinMode(PIN_SPI_DRDY, OUTPUT);
    digitalWrite(PIN_SPI_DRDY, LOW);

    // MISO collision fix: high-impedance INPUT initially
    pinMode(PIN_SPI_CS, INPUT_PULLUP);
    pinMode(PIN_SPI_MOSI, INPUT);
    pinMode(PIN_SPI_SCK, INPUT);
    pinMode(PIN_SPI_MISO, INPUT);

    attachInterrupt(digitalPinToInterrupt(PIN_SPI_CS), isr_cs_pin_transition, CHANGE);

    memset(&g_tx_packet, 0, sizeof(g_tx_packet));
    g_tx_packet.magic[0] = PONDEYES_MAGIC_0;
    g_tx_packet.magic[1] = PONDEYES_MAGIC_1;
    g_tx_packet.node_id = NODE_ID;
    g_tx_packet.sequence = 0;
    g_tx_packet.timestamp_ms = millis();
    g_tx_packet.target_count = 0;
    pondeyes_seal_packet_crc(&g_tx_packet);
}

void isr_cs_pin_transition() {
    int cs_val = digitalReadFast(PIN_SPI_CS);

    if (cs_val == LOW) {
        pinMode(PIN_SPI_MISO, OUTPUT);
        g_cs_active = true;

        const uint8_t* p_bytes = (const uint8_t*)&g_tx_packet;
        size_t total_len = sizeof(PondEyesSpiPacket_t);

        for (size_t b = 0; b < total_len; b++) {
            uint8_t out_byte = p_bytes[b];
            for (int bit = 7; bit >= 0; bit--) {
                while (digitalReadFast(PIN_SPI_SCK) == HIGH && digitalReadFast(PIN_SPI_CS) == LOW);
                digitalWriteFast(PIN_SPI_MISO, (out_byte & (1 << bit)) ? HIGH : LOW);
                while (digitalReadFast(PIN_SPI_SCK) == LOW && digitalReadFast(PIN_SPI_CS) == LOW);
            }
        }
    } else {
        pinMode(PIN_SPI_MISO, INPUT); // High-impedance tri-state
        digitalWriteFast(PIN_SPI_DRDY, LOW);
        g_cs_active = false;
    }
}

void loop() {
    for (int i = 0; i < 3; i++) {
        process_uart_port(&g_ports[i]);
    }

    bool fresh_data = false;
    for (int i = 0; i < 3; i++) {
        if (g_ports[i].new_data_available) {
            fresh_data = true;
            g_ports[i].new_data_available = false;
        }
    }

    if (fresh_data) {
        transform_targets_to_global();
        deduplicate_seam_targets();
        prepare_spi_packet();
    }

    uint32_t now_ms = millis();
    if (now_ms - g_last_debug_print_ms >= 1000) {
        g_last_debug_print_ms = now_ms;
        Serial.printf("[Node A] Uptime: %lu ms | Seq: %u | ActiveTargets: %u | S1: %lu pkts, S2: %lu pkts, S3: %lu pkts\n",
                      now_ms, g_packet_sequence, g_tx_packet.target_count,
                      g_ports[0].packets_parsed, g_ports[1].packets_parsed, g_ports[2].packets_parsed);
    }
}

void process_uart_port(SensorPort_t* port) {
    while (port->serial->available() > 0) {
        uint8_t byte_in = port->serial->read();

        switch (port->state) {
            case STATE_WAIT_HEADER_0:
                if (byte_in == LD2450_FRAME_HEAD_0) port->state = STATE_WAIT_HEADER_1;
                break;
            case STATE_WAIT_HEADER_1:
                port->state = (byte_in == LD2450_FRAME_HEAD_1) ? STATE_WAIT_HEADER_2 : STATE_WAIT_HEADER_0;
                break;
            case STATE_WAIT_HEADER_2:
                port->state = (byte_in == LD2450_FRAME_HEAD_2) ? STATE_WAIT_HEADER_3 : STATE_WAIT_HEADER_0;
                break;
            case STATE_WAIT_HEADER_3:
                if (byte_in == LD2450_FRAME_HEAD_3) {
                    port->payload_idx = 0;
                    port->state = STATE_READ_PAYLOAD;
                } else {
                    port->state = STATE_WAIT_HEADER_0;
                }
                break;
            case STATE_READ_PAYLOAD:
                port->payload_buf[port->payload_idx++] = byte_in;
                if (port->payload_idx >= 24) port->state = STATE_WAIT_TAIL_0;
                break;
            case STATE_WAIT_TAIL_0:
                if (byte_in == LD2450_FRAME_TAIL_0) {
                    port->state = STATE_WAIT_TAIL_1;
                } else {
                    port->frame_errors++;
                    port->state = STATE_WAIT_HEADER_0;
                }
                break;
            case STATE_WAIT_TAIL_1:
                if (byte_in == LD2450_FRAME_TAIL_1) {
                    parse_raw_payload(port);
                    port->packets_parsed++;
                    port->new_data_available = true;
                } else {
                    port->frame_errors++;
                }
                port->state = STATE_WAIT_HEADER_0;
                break;
            default:
                port->state = STATE_WAIT_HEADER_0;
                break;
        }
    }
}

void parse_raw_payload(SensorPort_t* port) {
    const uint8_t* buf = port->payload_buf;

    for (int t = 0; t < MAX_TARGETS_PER_SENSOR; t++) {
        int base = t * 8;
        uint16_t raw_x = (uint16_t)(buf[base + 0] | (buf[base + 1] << 8));
        int16_t x_mm = (raw_x & 0x8000) ? -((int16_t)(raw_x & 0x7FFF)) : (int16_t)(raw_x & 0x7FFF);

        uint16_t raw_y = (uint16_t)(buf[base + 2] | (buf[base + 3] << 8));
        int16_t y_mm = (raw_y & 0x8000) ? -((int16_t)(raw_y & 0x7FFF)) : (int16_t)(raw_y & 0x7FFF);

        uint16_t raw_speed = (uint16_t)(buf[base + 4] | (buf[base + 5] << 8));
        int16_t speed_cms = (raw_speed & 0x8000) ? -((int16_t)(raw_speed & 0x7FFF)) : (int16_t)(raw_speed & 0x7FFF);

        uint16_t dist_mm = (uint16_t)(buf[base + 6] | (buf[base + 7] << 8));

        port->raw_targets[t].x_mm = x_mm;
        port->raw_targets[t].y_mm = y_mm;
        port->raw_targets[t].speed_cms = speed_cms;
        port->raw_targets[t].distance_res_mm = dist_mm;

        if (dist_mm > 50 && dist_mm <= 6500 && y_mm > 0) {
            port->raw_targets[t].valid = 1;
        } else {
            port->raw_targets[t].valid = 0;
        }
    }
}

void transform_targets_to_global() {
    g_transformed_count = 0;

    for (int p = 0; p < 3; p++) {
        SensorPort_t* port = &g_ports[p];
        SensorGeometry_t* geom = &g_sensors[p];

        for (int t = 0; t < MAX_TARGETS_PER_SENSOR; t++) {
            if (!port->raw_targets[t].valid) continue;

            float x_local = (float)port->raw_targets[t].x_mm;
            float y_local = (float)port->raw_targets[t].y_mm;

            float dx = (x_local * geom->cos_val) + (y_local * geom->sin_val);
            float dy = (-x_local * geom->sin_val) + (y_local * geom->cos_val);

            float x_global = ARENA_GRID_CENTER_X_MM + geom->mount_x_mm + dx;
            float y_global = ARENA_GRID_CENTER_Y_MM + geom->mount_y_mm + dy;

            if (x_global < 0.0f) x_global = 0.0f;
            if (x_global > 10000.0f) x_global = 10000.0f;
            if (y_global < 0.0f) y_global = 0.0f;
            if (y_global > 10000.0f) y_global = 10000.0f;

            if (g_transformed_count < MAX_TARGETS_PER_NODE) {
                PondEyesTarget_t* tgt = &g_transformed_targets[g_transformed_count++];
                tgt->target_id    = (uint8_t)(t + 1);
                tgt->sensor_id    = geom->sensor_id;
                tgt->x_global_mm  = (int16_t)roundf(x_global);
                tgt->y_global_mm  = (int16_t)roundf(y_global);
                tgt->speed_cms    = port->raw_targets[t].speed_cms;
                tgt->distance_mm  = port->raw_targets[t].distance_res_mm;
                tgt->x_local_mm   = port->raw_targets[t].x_mm;
                tgt->y_local_mm   = port->raw_targets[t].y_mm;
                tgt->is_fused     = 0;
                tgt->source_mask  = (uint8_t)(1 << (geom->sensor_id - 1));
            }
        }
    }
}

void deduplicate_seam_targets() {
    if (g_transformed_count <= 1) return;

    bool merged[MAX_TARGETS_PER_NODE] = { false };

    for (int i = 0; i < g_transformed_count; i++) {
        if (merged[i]) continue;

        for (int j = i + 1; j < g_transformed_count; j++) {
            if (merged[j]) continue;

            if (g_transformed_targets[i].sensor_id != g_transformed_targets[j].sensor_id) {
                float dx = (float)(g_transformed_targets[i].x_global_mm - g_transformed_targets[j].x_global_mm);
                float dy = (float)(g_transformed_targets[i].y_global_mm - g_transformed_targets[j].y_global_mm);
                float dist_sq = (dx * dx) + (dy * dy);

                if (dist_sq < SEAM_DEDUP_DIST_SQ_MM) {
                    g_transformed_targets[i].x_global_mm = (int16_t)((g_transformed_targets[i].x_global_mm + g_transformed_targets[j].x_global_mm) / 2);
                    g_transformed_targets[i].y_global_mm = (int16_t)((g_transformed_targets[i].y_global_mm + g_transformed_targets[j].y_global_mm) / 2);
                    g_transformed_targets[i].speed_cms   = (int16_t)((g_transformed_targets[i].speed_cms + g_transformed_targets[j].speed_cms) / 2);
                    g_transformed_targets[i].distance_mm = (uint16_t)((g_transformed_targets[i].distance_mm + g_transformed_targets[j].distance_mm) / 2);
                    g_transformed_targets[i].is_fused    = 1;
                    g_transformed_targets[i].source_mask |= g_transformed_targets[j].source_mask;

                    merged[j] = true;
                }
            }
        }
    }

    uint8_t write_idx = 0;
    for (int i = 0; i < g_transformed_count; i++) {
        if (!merged[i]) {
            if (write_idx != i) {
                g_transformed_targets[write_idx] = g_transformed_targets[i];
            }
            write_idx++;
        }
    }
    g_transformed_count = write_idx;
}

void prepare_spi_packet() {
    g_tx_packet.magic[0]      = PONDEYES_MAGIC_0;
    g_tx_packet.magic[1]      = PONDEYES_MAGIC_1;
    g_tx_packet.node_id       = NODE_ID;
    g_tx_packet.sequence      = ++g_packet_sequence;
    g_tx_packet.timestamp_ms  = millis();
    g_tx_packet.target_count  = g_transformed_count;

    for (uint8_t i = 0; i < g_transformed_count; i++) {
        g_tx_packet.targets[i] = g_transformed_targets[i];
    }
    for (uint8_t i = g_transformed_count; i < MAX_TARGETS_PER_NODE; i++) {
        memset(&g_tx_packet.targets[i], 0, sizeof(PondEyesTarget_t));
    }

    pondeyes_seal_packet_crc(&g_tx_packet);
    digitalWriteFast(PIN_SPI_DRDY, HIGH);
}

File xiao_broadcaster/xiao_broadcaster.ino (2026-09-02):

/**
 * ============================================================================
 * PondEyes Omni-Lighthouse - Master Coordinator & Broadcaster Firmware
 * Microcontroller: Seeed Studio XIAO ESP32-S3 (240 MHz Dual-Core Xtensa LX7)
 * ============================================================================
 */

#include <Arduino.h>
#if __has_include(<HWCDC.h>)
#include <HWCDC.h>
#endif
#if __has_include(<HardwareSerial.h>)
#include <HardwareSerial.h>
#endif
#include <WiFi.h>
#include <PubSubClient.h>
#include <ArduinoJson.h>
#include <SPI.h>
#include <esp_task_wdt.h>
#if __has_include(<esp_attr.h>)
#include <esp_attr.h>
#endif

#ifndef IRAM_ATTR
#define IRAM_ATTR
#endif

// Arduino Core Timing & Utility Prototypes (C-linkage for IDE / Clangd / Toolchains)
#ifdef __cplusplus
extern "C" {
#endif
void delay(uint32_t ms);
void delayMicroseconds(uint32_t us);
unsigned long millis(void);
unsigned long micros(void);
void yield(void);
#ifdef __cplusplus
}
#endif
#if __has_include("../include/pondeyes_protocol.h")
#include "../include/pondeyes_protocol.h"
#elif __has_include("include/pondeyes_protocol.h")
#include "include/pondeyes_protocol.h"
#else
#include "pondeyes_protocol.h"
#endif

// ============================================================================
// HARDWARE PIN DEFINITIONS (Seeed Studio XIAO ESP32-S3)
// ============================================================================
#define PIN_SPI_SCK                 7   // D8 (GPIO 7) - SPI Clock Out (8 MHz)
#define PIN_SPI_MISO                8   // D9 (GPIO 8) - SPI MISO In (from Teensy nodes)
#define PIN_SPI_MOSI                9   // D10 (GPIO 9) - SPI MOSI Out (to Teensy nodes)

#define PIN_CS_NODE_A               2   // D1 (GPIO 2) - Chip Select for Teensy Node A
#define PIN_CS_NODE_B               3   // D2 (GPIO 3) - Chip Select for Teensy Node B

#define PIN_DRDY_NODE_A             4   // D3 (GPIO 4) - Data Ready Interrupt from Node A
#define PIN_DRDY_NODE_B             5   // D4 (GPIO 5) - Data Ready Interrupt from Node B

#define PIN_STATUS_LED              21  // Yellow User LED on XIAO ESP32-S3
#define WDT_TIMEOUT_SECONDS         8   // Hardware Watchdog Period

// ============================================================================
// NETWORK & MQTT CONFIGURATION
// ============================================================================
const char* WIFI_SSID               = "PondEyes_Field_AP";
const char* WIFI_PASSWORD           = "OmniLighthouse2026";

const char* MQTT_BROKER_HOST        = "192.168.1.100";
const uint16_t MQTT_BROKER_PORT     = 1883;
const char* MQTT_CLIENT_ID          = "PondEyes_Lighthouse_Coord";
const char* MQTT_USER               = "";
const char* MQTT_PASS               = "";

const char* TOPIC_LIGHTHOUSE_BASE   = "PondEyes/lighthouse/";
const char* TOPIC_FUSED_SUMMARY     = "PondEyes/lighthouse/fused";
const char* TOPIC_HEARTBEAT         = "PondEyes/lighthouse/telemetry";

#define BROADCAST_INTERVAL_MS       100

// ============================================================================
// STATIC MEMORY ALLOCATION (ZERO HEAP FRAGMENTATION)
// ============================================================================
static WiFiClient           g_wifi_client;
static PubSubClient         g_mqtt_client(g_wifi_client);

static StaticJsonDocument<2048> g_static_json_doc;
static char                 g_mqtt_payload_buffer[2048];

static PondEyesSpiPacket_t  g_packet_node_a;
static PondEyesSpiPacket_t  g_packet_node_b;

static PondEyesTarget_t     g_latest_targets_a[MAX_TARGETS_PER_NODE];
static uint8_t              g_latest_count_a = 0;
static uint32_t             g_last_seen_node_a_ms = 0;

static PondEyesTarget_t     g_latest_targets_b[MAX_TARGETS_PER_NODE];
static uint8_t              g_latest_count_b = 0;
static uint32_t             g_last_seen_node_b_ms = 0;

static volatile bool        g_drdy_flag_a = false;
static volatile bool        g_drdy_flag_b = false;

static uint32_t             g_spi_success_a = 0;
static uint32_t             g_spi_crc_err_a = 0;
static uint32_t             g_spi_success_b = 0;
static uint32_t             g_spi_crc_err_b = 0;
static uint32_t             g_mqtt_pub_count = 0;
static uint32_t             g_last_broadcast_ms = 0;
static uint32_t             g_last_heartbeat_ms = 0;

static uint32_t             g_wifi_backoff_ms = 1000;
static uint32_t             g_last_wifi_attempt_ms = 0;
static const uint32_t       WIFI_MAX_BACKOFF_MS = 30000;

void IRAM_ATTR isr_drdy_node_a();
void IRAM_ATTR isr_drdy_node_b();
void init_gpio_and_spi();
void init_watchdog();
void maintain_wifi_exponential_backoff();
void maintain_mqtt_connection();
bool read_node_spi(uint8_t cs_pin, PondEyesSpiPacket_t* dest_packet);
void publish_sensor_payloads_10hz();
void publish_fused_summary_json();
void publish_system_heartbeat();

void setup() {
    Serial.begin(115200);
    delay(1000);

    Serial.println(F("\n========================================================"));
    Serial.println(F(" PondEyes Omni-Lighthouse: MASTER COORDINATOR (ESP32-S3)"));
    Serial.println(F(" Dual SPI Master -> 10Hz Static-Memory MQTT Broadcaster"));
    Serial.println(F("========================================================"));

    init_gpio_and_spi();
    init_watchdog();

    g_mqtt_client.setServer(MQTT_BROKER_HOST, MQTT_BROKER_PORT);
    g_mqtt_client.setBufferSize(2048);
    g_mqtt_client.setKeepAlive(15);

    maintain_wifi_exponential_backoff();

    Serial.println(F("[Broadcaster] Initialization complete. Entering high-reliability loop."));
}

void init_gpio_and_spi() {
    pinMode(PIN_STATUS_LED, OUTPUT);
    digitalWrite(PIN_STATUS_LED, HIGH);

    pinMode(PIN_CS_NODE_A, OUTPUT);
    pinMode(PIN_CS_NODE_B, OUTPUT);
    digitalWrite(PIN_CS_NODE_A, HIGH);
    digitalWrite(PIN_CS_NODE_B, HIGH);

    pinMode(PIN_DRDY_NODE_A, INPUT_PULLDOWN);
    pinMode(PIN_DRDY_NODE_B, INPUT_PULLDOWN);
    attachInterrupt(digitalPinToInterrupt(PIN_DRDY_NODE_A), isr_drdy_node_a, RISING);
    attachInterrupt(digitalPinToInterrupt(PIN_DRDY_NODE_B), isr_drdy_node_b, RISING);

    SPI.begin(PIN_SPI_SCK, PIN_SPI_MISO, PIN_SPI_MOSI);

    digitalWrite(PIN_STATUS_LED, LOW);
}

void init_watchdog() {
    esp_task_wdt_init(WDT_TIMEOUT_SECONDS, true);
    esp_task_wdt_add(NULL);
    esp_task_wdt_reset();
}

void IRAM_ATTR isr_drdy_node_a() {
    g_drdy_flag_a = true;
}

void IRAM_ATTR isr_drdy_node_b() {
    g_drdy_flag_b = true;
}
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

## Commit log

2026-09-18 feat: add mechanical CAD exports and hardware dimensions
    [bottom_tot.stl, sensor_tot.stl, top_tot.stl]
2026-09-18 docs: add 3D model enclosure specification
2026-09-18 refactor: rename mechanical folder to 3D models
    [bottom_tot.stl, sensor_tot.stl, top_tot.stl]
2026-09-19 docs: document Blender source files and STL mappings
2026-10-11 docs: document sensor model dimensions and STL scale validation
2026-10-11 docs: update enclosure and sensor body dimensions
2026-10-11 docs: add sensor body print specification
2026-10-11 Replace placeholder STLs with dimension-validated 3D models
    - sensor_tot.stl: corrected to authoritative 62.70 × 62.11 × 125.00 mm
    (Blender Scale 0.10 was unapplied; vertices rescaled to match screenshot)
    - top_tot.stl and bottom_tot.stl: real binary meshes replacing 14-16 byte stubs
    - Add sensor_tot_dimensions_blender.png (source of the 62.70/62.11/125.00 mm values)
    - Update README.md, PondEyes_Enclosure_Spec.md and sensor_tot/README.md
    with scale-correction notes and print checklist
    Old placeholder files (14-16 bytes) have been overwritten and are no longer present.

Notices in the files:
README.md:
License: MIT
